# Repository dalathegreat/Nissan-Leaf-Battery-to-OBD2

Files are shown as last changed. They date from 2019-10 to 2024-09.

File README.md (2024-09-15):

# Nissan-Leaf-Battery-to-OBD2
An opensource solution for connecting OBD2 straight to a Nissan Leaf battery. Very useful gadget to have if you're thinking about buying a battery and want to check the state-of-health beforehand.

Please note, there are two versions of the 'Yazaki' connector found on Nissan Leaf batteries. This connector is refered to as the B24 connector in service manuals. The 2011-2012 version uses a 21-pin, and the 2013-2019 uses a 36-pin connector. See the documentation folder for the schematic differences

## 2013+
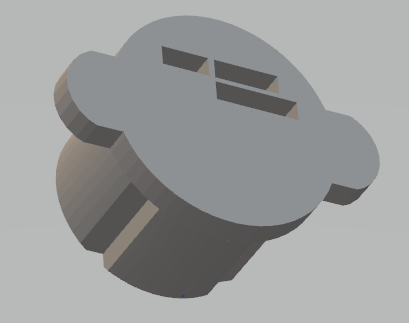
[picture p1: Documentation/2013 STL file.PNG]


## 2011-2012
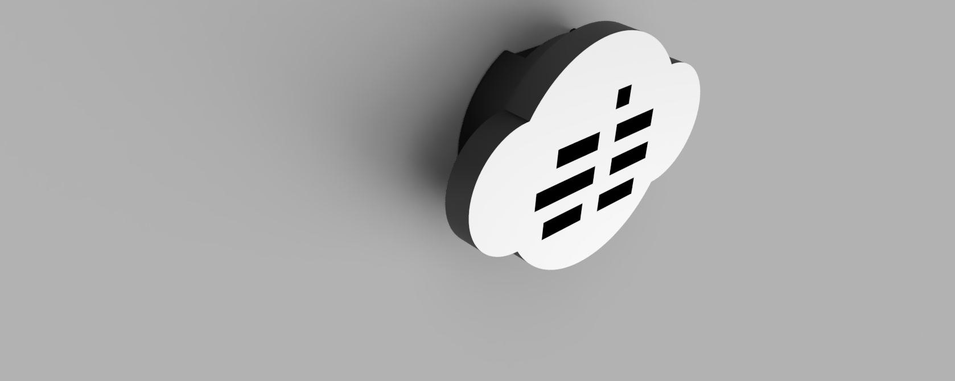
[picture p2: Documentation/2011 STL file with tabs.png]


A proper Yazaki 22-pin as reference:


# How to make your own
It's really easy to make, you'll need the following items:
1. 3d-printed 'B24' connector, found in this repository (for those without a 3d-printer, a ready to go 2013-2019 36 pin connector is available here: https://aliexpress.com/item/1005004180391674.html => in this case you don't need the items needed described in 2. and 3.
2. Dupont style connectors (found in most arduino kits or old PCs) [2013+ use 1x2, 1x3, 1x4, or 2011-2012 version 1x1 only] [Here's what they look like](Documentation/WhatDoDupontCablesLookLike.PNG)
3. Superglue / Epoxy
4. An OBD2 port along with the pins (can be bought new or salvaged from a scrap car)
5. Wires to connect it all
6. A 12V power source (small lead acid battery does the trick OR a few 18650s in series)

# Printing tips
This design has been printed with PLA and PETG. Very likely to work with ABS too! Print with low speed to get the mounting holes to be perfectly shaped. There isn't much to gain with higher quality, the connector will work just fine at .12/.16/.20/.28 mm layer height. Infill settings doesn't matter much as long as it's above 20%. No supports needed! Printing should take ~1.5h

# Detailed instructions
To start of with, gather all the parts needed. Take the correct B24 connector from this repository. Once you have the model printed, attach dupont connectors to it by supergluing/epoxying them in place. Be careful not to get any glue inside the connector, especially the pins. Less is more when it comes to the glue. Once the glue has dried its time to connect the B24 wiring to the OBD2 port wiring. Solder or crimp the connectors together according to the schematic diagram. Power it up with an external +12V source or battery. 12V lead acid or 3x18650s in series works well.

To read data from the pack, plug in an OBD2 bluetooth dongle to the port and fire up Leafspy. Go into the settings menu, and switch to 'BMS only' mode. This can be found where you select your model year, scroll up the list and where 2010 should be there is a 'BMS only' option.

If you did everything correctly, you schould end up with this.
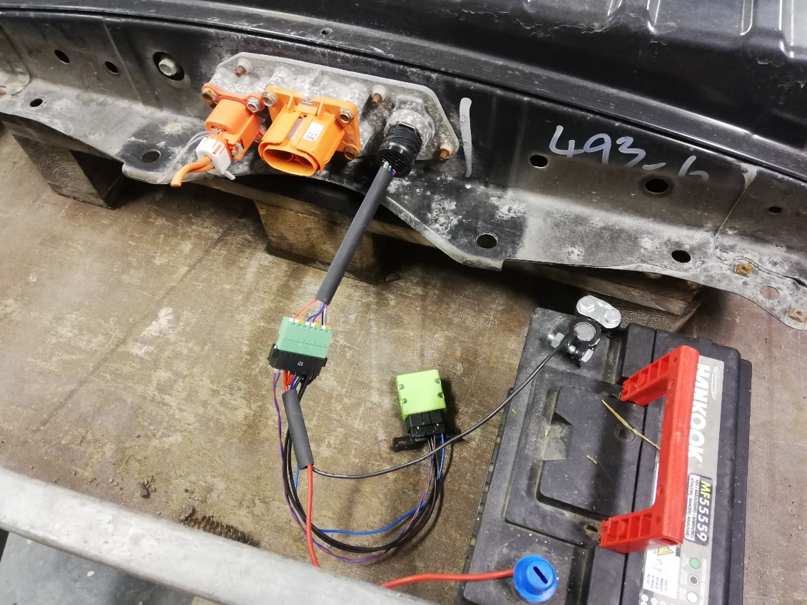
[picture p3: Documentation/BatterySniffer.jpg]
fully assembled


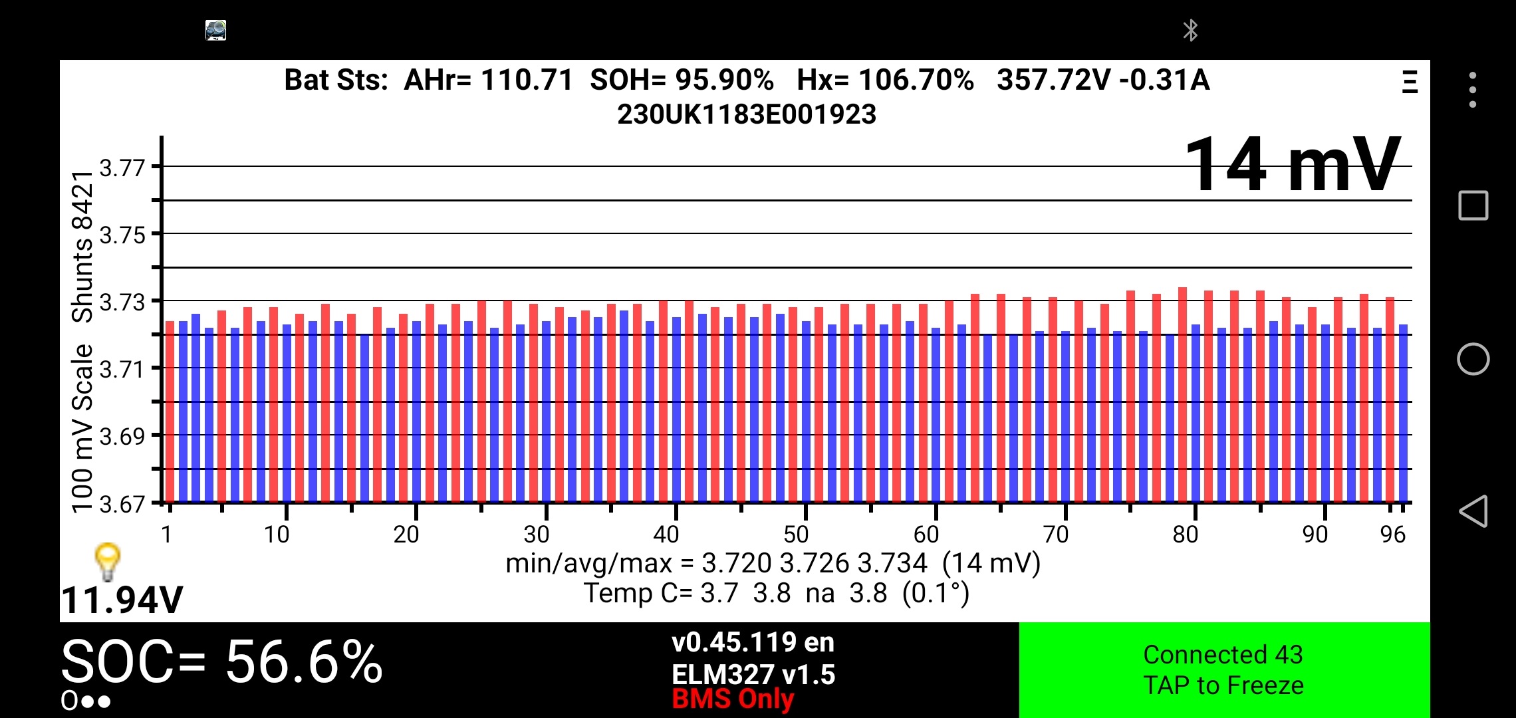
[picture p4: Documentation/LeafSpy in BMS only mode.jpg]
leaf spy screenshot


# Schematic
Here's the schematic for how to wire up the 2013+ connector to an OBD2 port
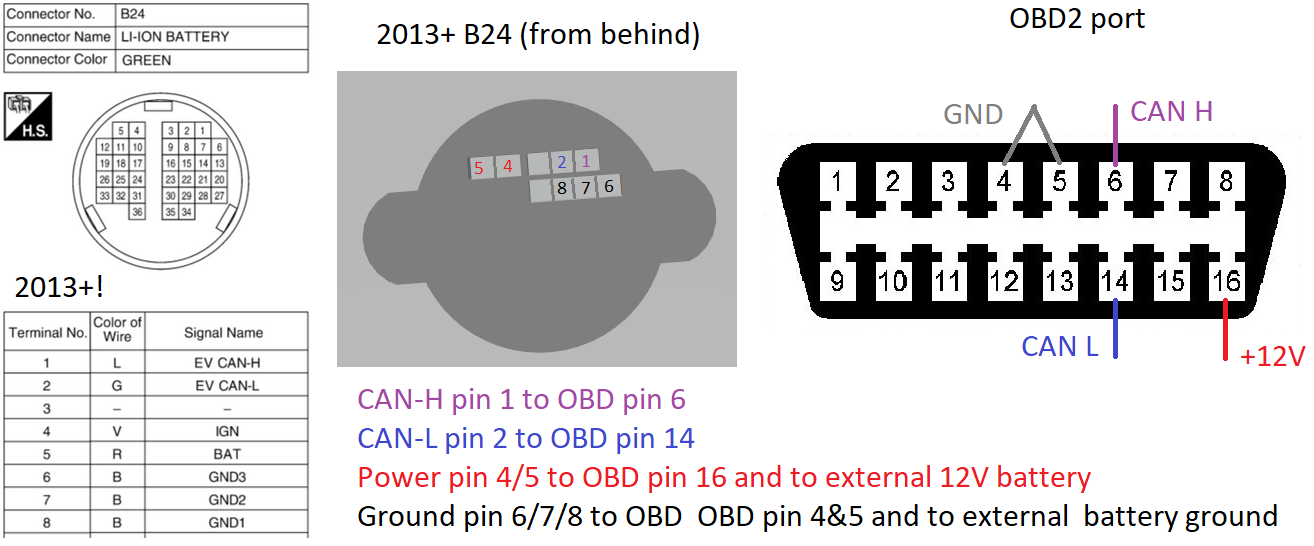
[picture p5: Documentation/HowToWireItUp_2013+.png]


For the 2011-2012, it's the same, but note the B24 connector pin locations differ - see the [2011-2012 pinouts](Documentation/2011_B24.jpg).

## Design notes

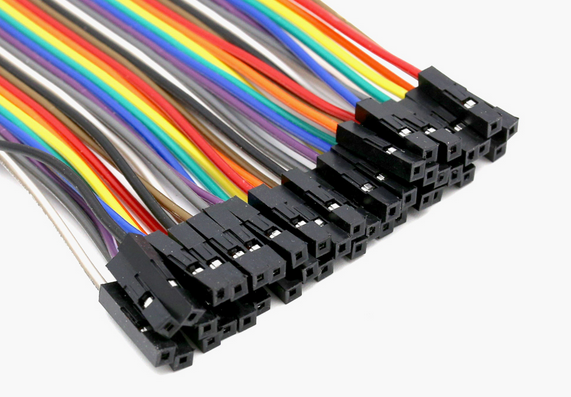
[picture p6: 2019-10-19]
Documentation/WhatDoDupontCablesLookLike.PNG

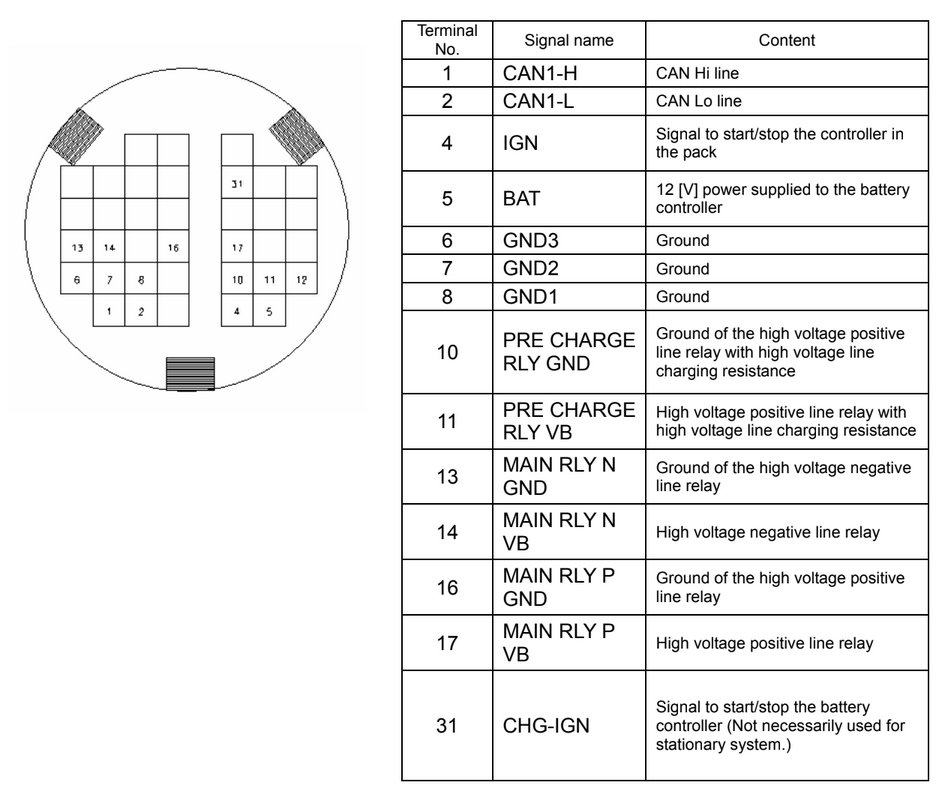
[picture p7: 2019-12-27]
Documentation/ExtraInformationB24_AZE0.PNG

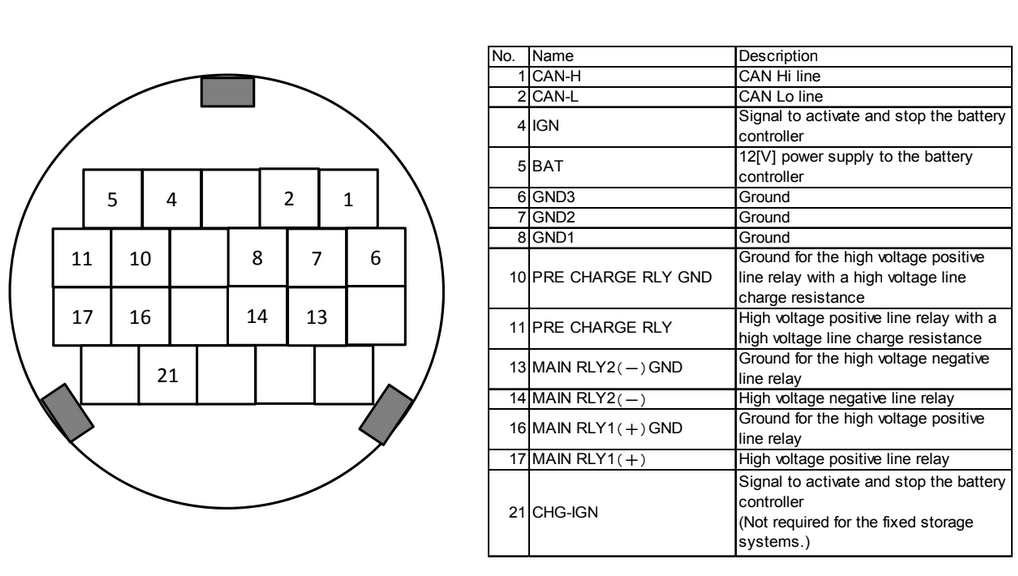
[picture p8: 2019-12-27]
Documentation/ExtraInformationB24_ZE0.PNG

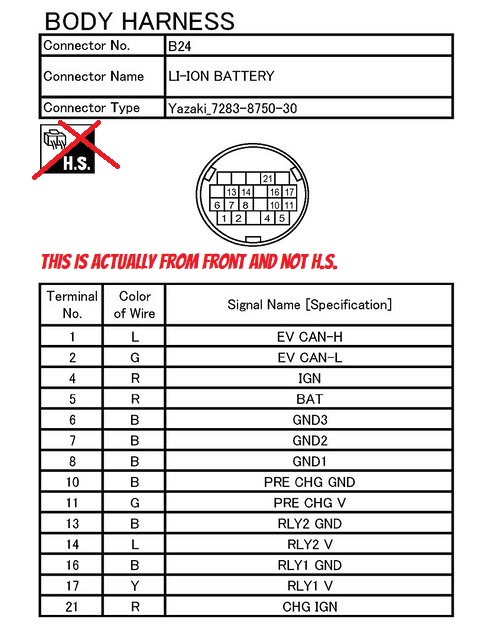
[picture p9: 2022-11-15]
Documentation/2011_B24.jpg

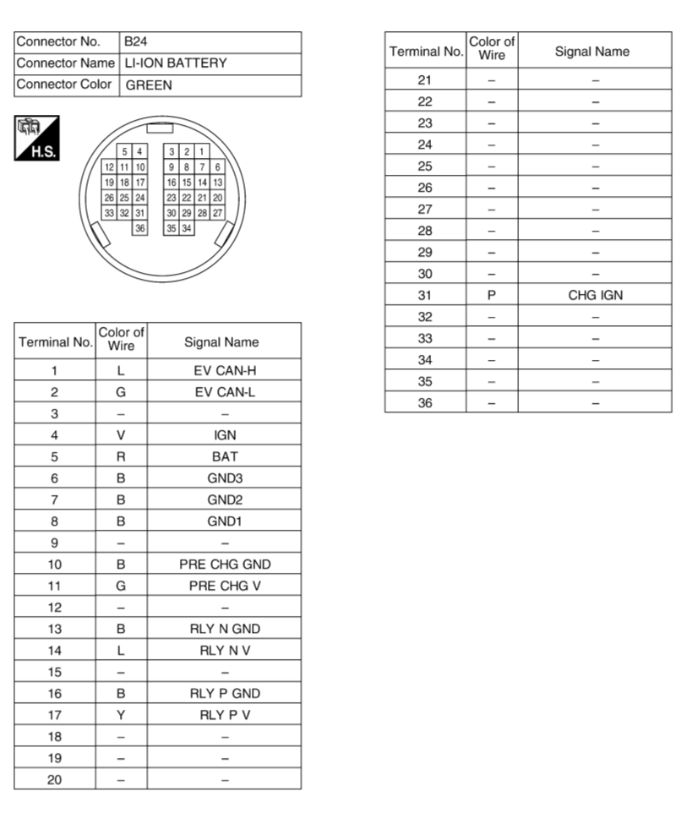
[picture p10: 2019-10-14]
Documentation/2013_B24.PNG

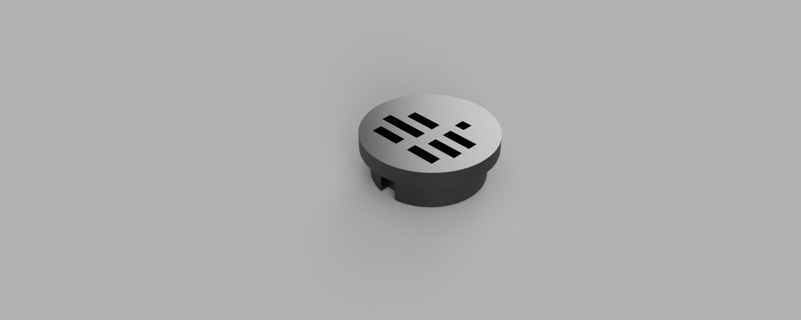
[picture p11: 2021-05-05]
Documentation/2011 STL file.png

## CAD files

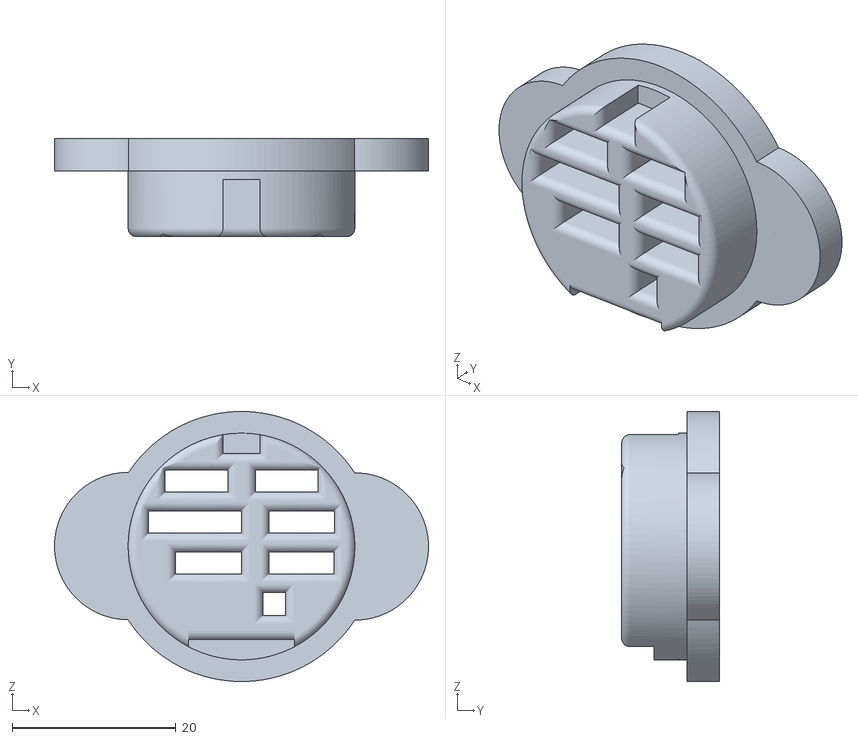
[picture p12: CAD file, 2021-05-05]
B24_2011-2012 with tabs.stl
45.7 x 12.0 x 33.0

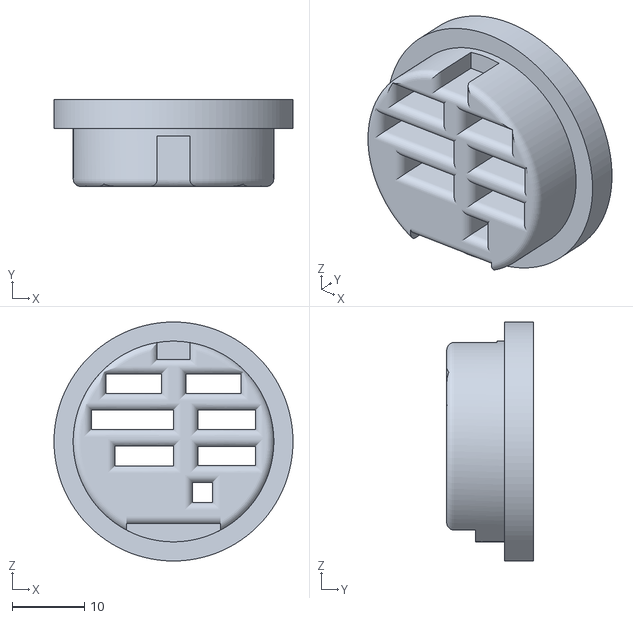
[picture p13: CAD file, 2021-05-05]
B24_2011-2012.stl
33.0 x 12.0 x 33.0

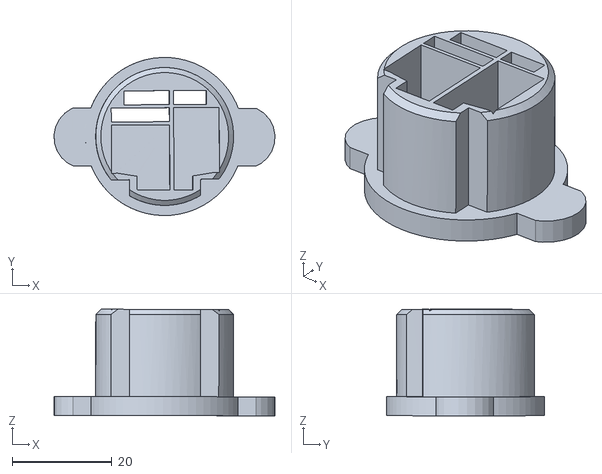
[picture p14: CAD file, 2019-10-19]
B24_2013+.stl
44.4 x 31.7 x 21.4

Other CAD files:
B24_2011-2012 with tabs.f3d
B24_2011-2012.f3d

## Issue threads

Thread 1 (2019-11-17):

21 pin B4 compatible STL file

PaulKennett, 2019-11-17:
You may be interested in my 21 pin version of the B24 plug and socket:

https://www.myminifactory.com/object/3d-print-nissan-leaf-b24-compatible-connector-93715

Cheers, Paul

cgalpin, 2021-04-24:
I had not noticed that you had made a 21 pin connector @PaulKennett before making my own! I probably should make a locking ring too, but it's not really needed for just the Nissan-Leaf-Battery-to-OBD2.

@dalathegreat mine is just the connector similar to your 2013+ one, and can make a merge request with updated documentation if interested.

dalathegreat, 2021-04-28:
@cgalpin Absolutely feel free! :)

PaulKennett, 2021-04-28:
@cgalpin Yeah - If you ever do print one with the locking ring - add a little grease to the inside of the ring to get a smooth slide action.

cgalpin, 2021-05-04:
Ok @dalathegreat, pull request #2 created.

@PaulKennett, I did not take the time to make a locking ring. I had not looked at yours before making mine (and if I had, I likely would not have bothered to make my own), nor am I sure if yours would be compatible - but if you think it would bet, let me know.

Closed 2024-08-20.

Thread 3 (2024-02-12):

Install ZE0 battery to AZE0 car

maheshsachintha, 2024-02-12:
I am going to install ZE0 battery to AZE0 car. According to the PIN config of connectors, used only same named  pins. Why we can't create physical adaptor to connect old battery to AZE0 car? Why we want to reassemble cells
 to AZE0 casin and BMS to plug ZE0  battery to AZE0 car? Is it required can bridge?
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

Closed 2024-08-20.

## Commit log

2019-10-14 Add picture of different B24 connectors
2019-10-14 Add initial version of B24 2013+ connector
    [B24_2013+.skp]
2019-10-15 Add proto that prints really quickly
    [ImprovedPrintSpeed.skp]
2019-10-15 Add initial STL file for 2013+ B24
    [B24_2013+.stl]
2019-10-16 Add picture of 2013+ connector STL file
2019-10-16 Add picture of Leafspy BMS only mode
2019-10-19 Add ears to make it easier to pull out connector
    [B24_2013+.stl.stl]
2019-10-19 Add initial B24 2013+ model
    [B24_2013+.stl]
2019-10-19 Add schematic for wiring
2019-10-19 Add preview of STL file
2019-12-27 Add file with more info about pins on B24
    Add file with more info about pins on B24 connector
2019-12-27 Add image with extra info on AZE0 B24
    Add image with extra info on AZE0 B24 connector
2019-12-27 Add extra info on B24 ZE0 connector
2021-05-04 Add 2011-2012 files
    [B24_2011-2012 with tabs.f3d, B24_2011-2012 with tabs.stl, B24_2011-2012.f3d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]
2024-08-20 Update README.md
    added link for a ready to go 2013-2019 36 pin connector
